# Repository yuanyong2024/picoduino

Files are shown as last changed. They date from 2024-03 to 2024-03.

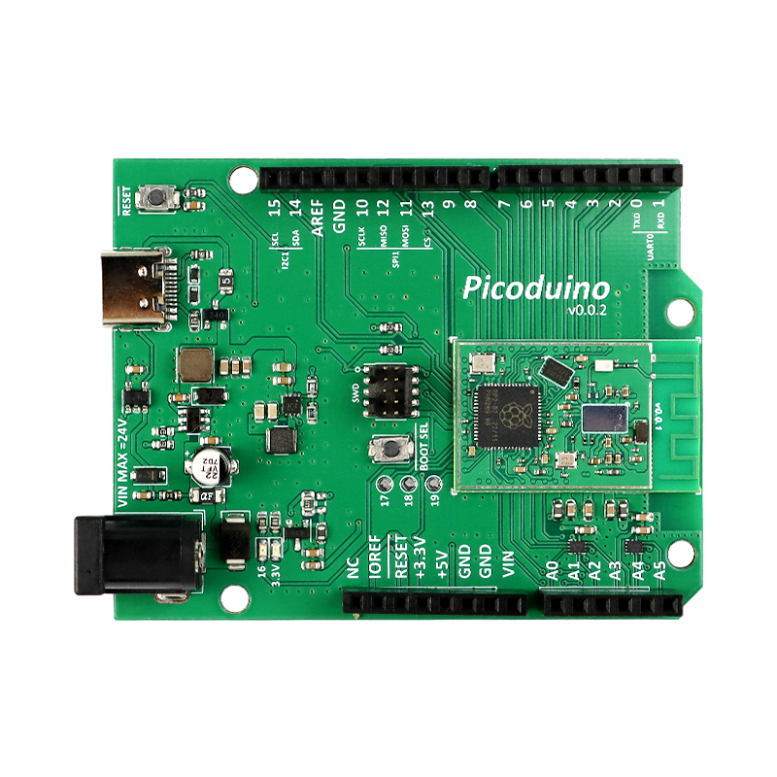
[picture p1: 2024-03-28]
pictures/6.jpg

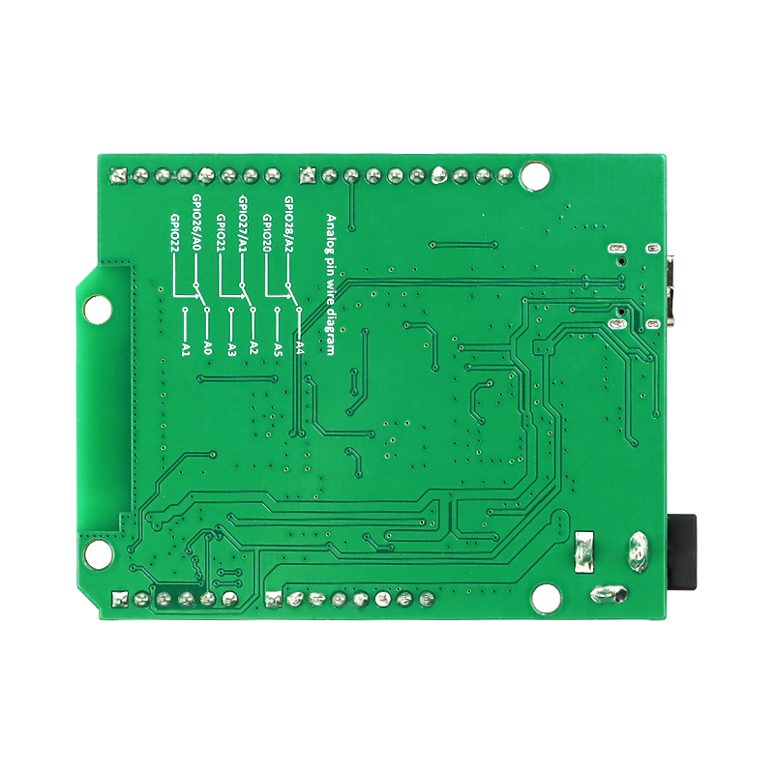
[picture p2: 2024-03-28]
pictures/5.jpg

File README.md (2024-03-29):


# Introduction
This is a Raspberry Pi Pico W hardware in arduino form factor.And it's name is picoduino

Unlike all the other wireless solutions for RP2040 on market(which almost all use the ESP wireless chip).
This board is equipped with a module that have the same chipsets like Pico W from Raspberry Pi. A microcontroller RP2040 from Raspberry Pi and a wireless chip CY43439 from Infineon.

# Features
1. totally compatible with arduino form factor.
2. fw developed for pico  w can easily ported to picoduino without any change(especially all the wireless features).
3. using analog switch so that 3 ADC ports can connect to 6 pins from A0 to A5 on picoduino board.
4. use a dedicated voltage reference to improve the accuracy of the ADC.
5. use two DC-DC regulators instead of LDO to improve the efficiency as well as increasing the maximum input voltage to 24V.
6. exposed all the GPIOs from RP2040 chip.
7. USB type C interface.
8. all the deisgn files are open-sourced and designed in Kicad.
    
# Limitations
1. During my test, I found out the antenna's performance still cannot match the official Pico w.
2. Still need more time and energy to tuning the antenna
3. No shield cover for the module on this version yet.
   
# considering support me?
Building the module and the picoduino definitley take time and energy.And also it's cost a lot. The module itself is a six layer board and I'm using the expensive Infineon chip. 
So I would appreciate anyone who can support me by purchase it from [this link](https://www.elecrow.com/picoduino.html)

# setup
For every board that you purchased, it's preflashed with a fw that can easily connect to local network as long as the wifi is available.
1. Plug picoduino to computer via USB type C cable.(A serial port should be available now)
2. Use some serial debug tool like arduino IDE's tool and type in your local WiFi name and then click send to send the WiFi name to picoduino.
3. it then will show the input WiFi name and ask you to type the password.
4. And send the password, picoduino will try to connect to the WiFi network with quick blink green led.
5. Once success, it will keep the green led on and you can copy the ip address to browser and then hit enter.
6. A webpage for controlling the green led is alive and you can control the led by click the webpage buttons.

setup_1

setup_2

# What's next?
After this picoduino, I will design a adafruit feather compatible one by using the same pico w module.
I will also make a programmable power supplier shield for picoduino.
## Stay tuned!

# useful links:
[pico w datasheet](https://datasheets.raspberrypi.com/picow/pico-w-datasheet.pdf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..)

[raspberry pi pico documentation](https://www.raspberrypi.com/documentation/microcontrollers/raspberry-pi-pico.html#raspberry-pi-pico-w)

[pico w module design file](https://github.com/yuanyong2024/pico_w_module)

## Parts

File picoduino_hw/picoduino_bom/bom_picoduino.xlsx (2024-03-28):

Ref | Qnty | Value | Footprint | PN | Vendor | Price(MOQ=100)
C1 | 1 | 47uF | Capacitor_SMD:CP_Elec_4x3 | EEEFT1V220AR | SAMSUNG | 1.02
C2, C6, C8, C11, C13, C14, C15, C16, C17, C18, C19 | 11 | 0.1uF | Capacitor_SMD:C_0603_1608Metric | 0603B104K500NT | FH | 0.014
C3 | 1 | 10nF | Capacitor_SMD:C_0603_1608Metric | 0603B103K500NT | FH | 0.015
C4,C7, C9, C20,C10 | 5 | 22uF | Capacitor_SMD:C_0603_1608Metric | CL10A226MP8NUNE | SAMSUNG | 0.084
C5, C12 | 2 | 4.7uF | Capacitor_SMD:C_0603_1608Metric | CL10A475KO8NNNC | SAMSUNG | 0.065
D1 | 1 | 30V | Diode_SMD:D_SMB | SSB44-E3/52T (https://item.szlcsc.com/472485.html) | VISHAY | 0.7
D2 | 1 | RED LED | LED_SMD:LED_0603_1608Metric | 19-213/R6C-AP1Q2B/5T | EVERLIGHT | 0.17
D4 | 1 | GREEN LED | LED_SMD:LED_0603_1608Metric | 19-213/GHC-XS1T1N/5T | EVERLIGHT | 0.3
D3 | 1 | 3A | Diode_SMD:D_SOD-123F | DSK34 | TWGMC | 0.16
D5 | 1 | 4.7V | Diode_SMD:D_SOD-123F | MMSZ4688T1G | onsemi | 0.27
D6, D7 | 2 | ESD5Zxx | Diode_SMD:D_SOD-523 | PESD5V0S1BB | TECH PUBLIC | 0.11
F1 | 1 | 500mA | Fuse:Fuse_1206_3216Metric | nSMD050-33V | luhai | 0.25
F2 | 1 | 500mA | Fuse:Fuse_0805_2012Metric | SMD0805B050TF | Brightking | 0.11
FB1, FB2, FB3 | 3 | FerriteBead | Inductor_SMD:L_0603_1608Metric | BLM18AG601SN1D | muRata | 0.037
J2 | 1 | Conn_ARM_JTAG_SWD_10 | Connector_PinHeader_1.27mm:PinHeader_2x05_P1.27mm_Vertical_SMD | HB-PH9-12725PB2GOB | HANBO | 0.45
J3 | 1 | USB_C_Receptacle_USB2.0 | Connector_USB:USB_C_Receptacle_HRO_TYPE-C-31-M-12 | TYPE-C 16PIN 2MD(073) | SHOU HAN | 0.28
J4, J7 | 2 | Conn_01x08 | Connector_PinSocket_2.54mm:PinSocket_1x08_P2.54mm_Vertical | PM254-1-08-Z-8.5 | HCTL | 0.65
J5 | 1 | Barrel_Jack_Switch_Pin3Ring | Connector_BarrelJack:BarrelJack_GCT_DCJ200-10-A_Horizontal | DC-005-20A | HRO | 0.46
J8 | 1 | Conn_01x10 | Connector_PinSocket_2.54mm:PinSocket_1x10_P2.54mm_Vertical | PM254-1-10-Z-8.5 | HCTL | 0.77
J9 | 1 | Conn_01x06 | Connector_PinSocket_2.54mm:PinSocket_1x06_P2.54mm_Vertical | PM254-1-06-W-8.5 | HCTL | 0.61
L1 | 1 | 6.8uH | Inductor_SMD:L_Abracon_ASPI-4030S | YHNR4020-6R8M | YJYCOIN | 0.45
L2 | 1 | 1.5uH | Inductor_SMD:L_Abracon_ASPI-3012S | FNR3012S1R5NT | CJIANG | 0.212
Q1 | 1 | FDN340P | Package_TO_SOT_SMD:SOT-23 | FDN340P | TECH PUBLIC | 0.3
R1 | 1 | 6K | Resistor_SMD:R_0805_2012Metric | 0603WAF1002T5E (https://item.szlcsc.com/26547.html) | UNI-ROYAL | 0.0057
R3 | 1 | 62K 1% | Resistor_SMD:R_0603_1608Metric | 0603WAF6202T5E | UNI-ROYAL | 0.0067
R4 | 1 | 12K 1% | Resistor_SMD:R_0603_1608Metric | 0603WAF1202T5E | UNI-ROYAL | 0.0061
R5, R13 | 2 | 4.7K | Resistor_SMD:R_0603_1608Metric | 0603WAF4701T5E | UNI-ROYAL | 0.0065
R12 | 1 | 10K | Resistor_SMD:R_0603_1608Metric | 0603WAF1002T5E | UNI-ROYAL | 0.0057
R6 | 1 | 1M | Resistor_SMD:R_0603_1608Metric | 0603WAF1004T5E | UNI-ROYAL | 0.006
R7, R11 | 2 | DNI | Resistor_SMD:R_0603_1608Metric
R8 | 1 | 20K 1% | Resistor_SMD:R_0603_1608Metric | 0603WAF2002T5E (https://item.szlcsc.com/4591.html) | UNI | 0.006
R9 | 1 | 90K 1% | Resistor_SMD:R_0603_1608Metric | 0603WAF9002T5E (https://item.szlcsc.com/2905674.html) | UNI-ROYAL | 0.006
R10, R14 | 2 | 1K | Resistor_SMD:R_0603_1608Metric | 0603WAF1001T5E | UNI-ROYAL | 0.005
R15, R16 | 2 | 5.1K | Resistor_SMD:R_0603_1608Metric | 0603WAF5101T5E | UNI-ROYAL | 0.006
SW1, SW2 | 2 | ~ | Button_Switch_SMD:SW_Push_SPST_NO_Alps_SKRK | YTS1C0191ABG00N | YIYUAN | 0.46
U1 | 1 | PICO_M | kiCadPcbLib:PICO_M
U2 | 1 | RT5797ALGQW | Package_DFN_QFN:DFN-8-1EP_2x2mm_P0.5mm_EP0.6x1.2mm | RT5797ALGQW | RICHTEK | 1.6
U3 | 1 | RT8259GE | Package_TO_SOT_SMD:SOT-23-6 | RT8259GE | RICHTEK | 2.5
U4 | 1 | OP | Package_TO_SOT_SMD:TSOT-23-5 | TL081HIDBVR | TI | 0.7
U5 | 1 | LM4040DBZ-3.0 | Package_TO_SOT_SMD:SOT-23-3 | LM4040B30FTA | DIODES | 2.84
U6, U7 | 2 | RS2118YUTQK10 | Package_DFN_QFN:UQFN-10_1.4x1.8mm_P0.4mm | RS2118YUTQK10 | RUNIC | 1.55

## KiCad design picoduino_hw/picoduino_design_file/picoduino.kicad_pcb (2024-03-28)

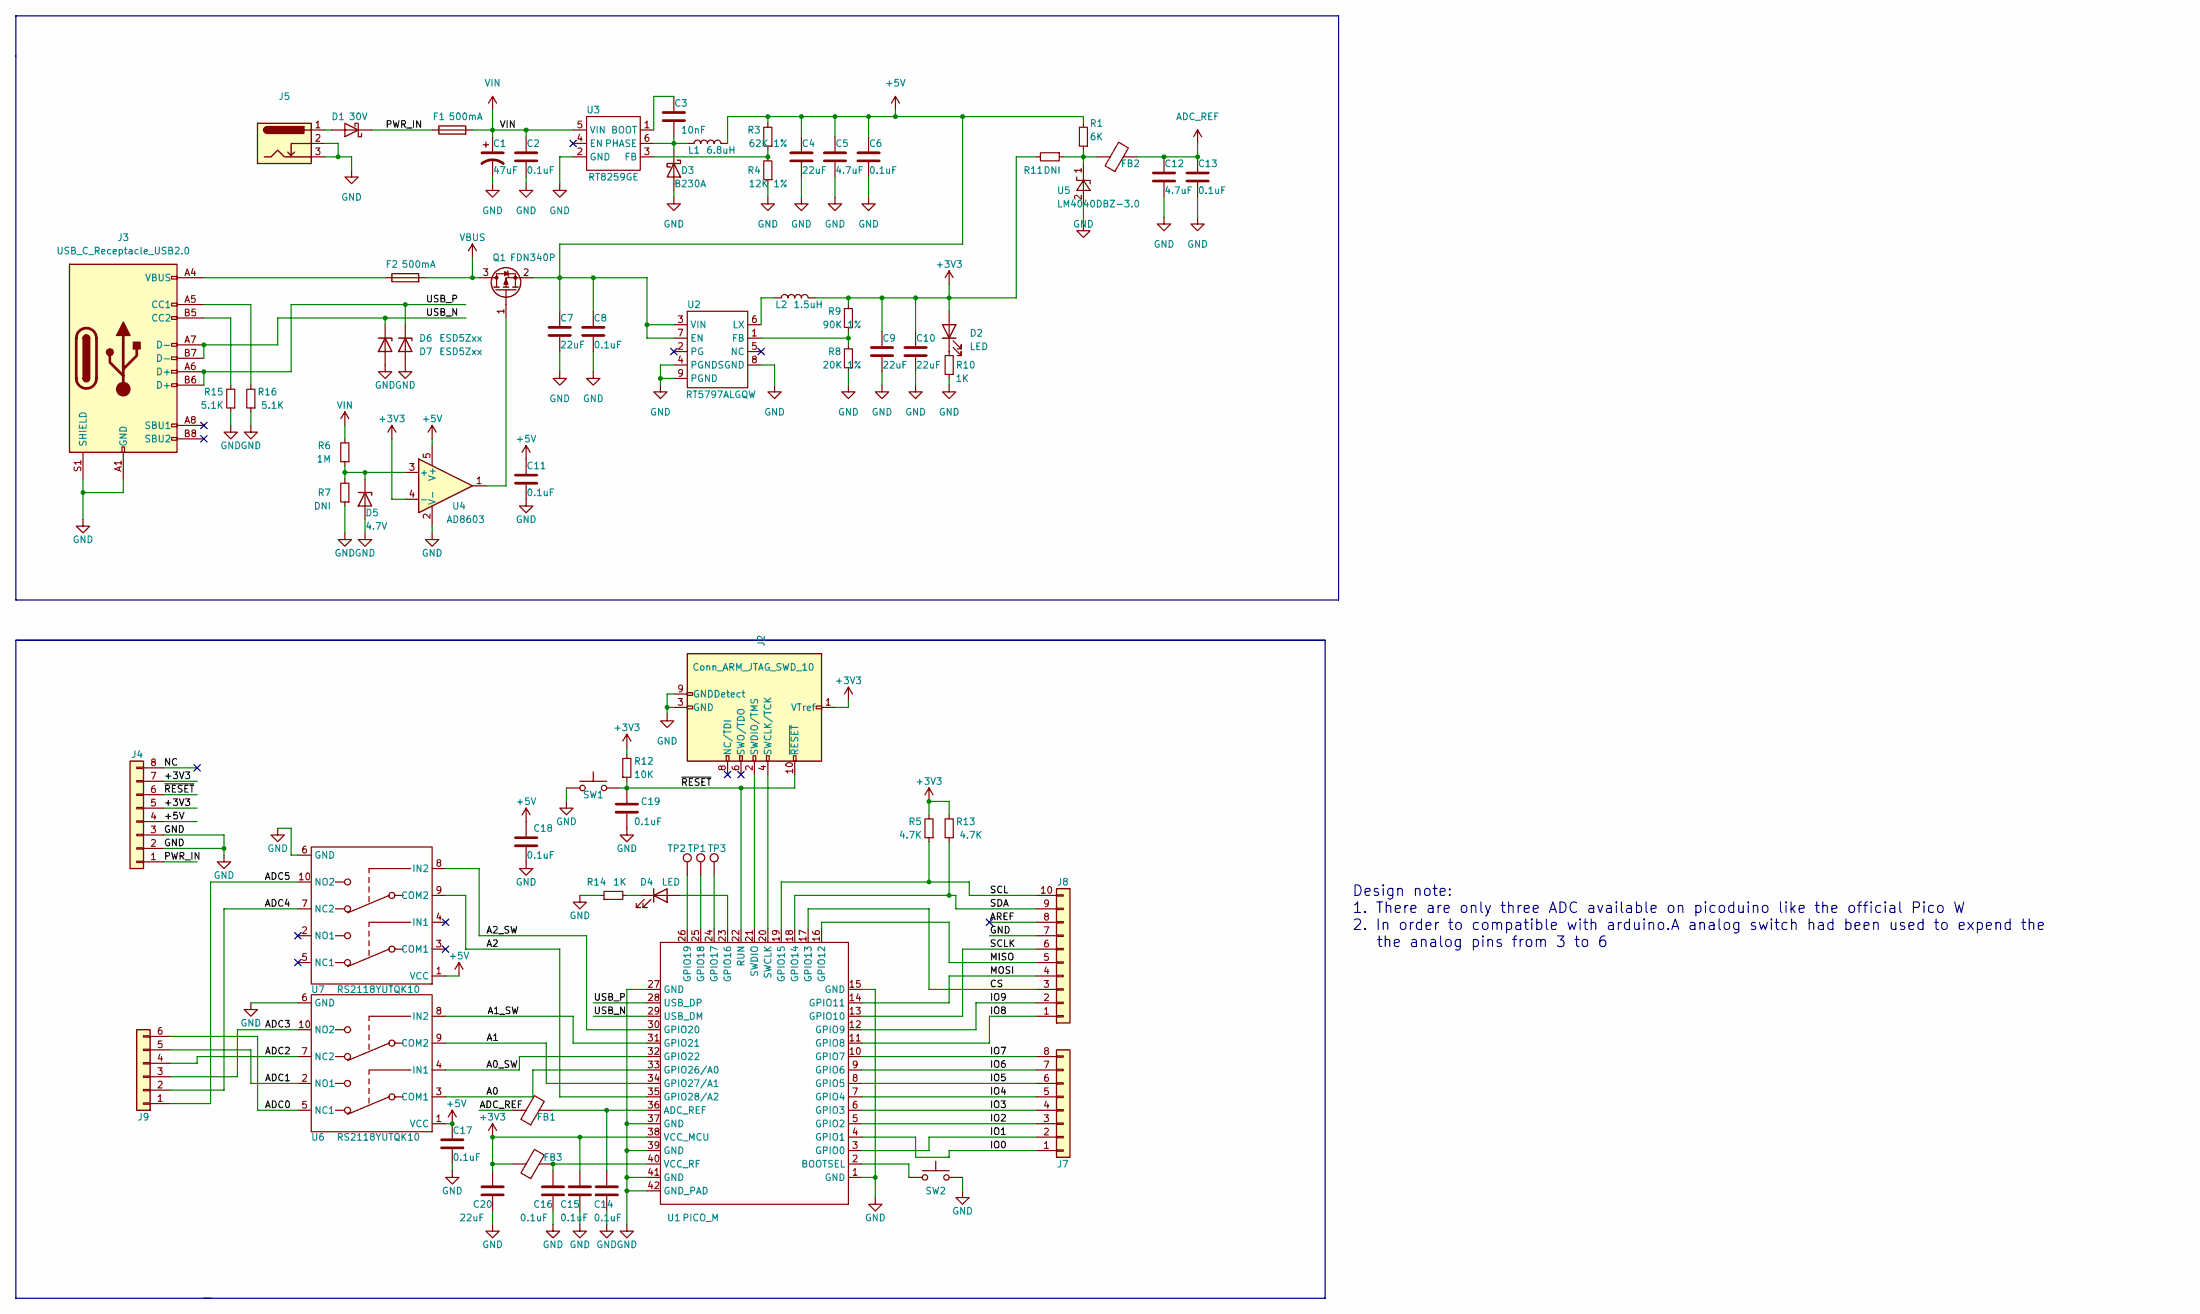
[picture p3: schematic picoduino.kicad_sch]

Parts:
C1: 47uF; CP_Elec_4x3
C2, C6, C8, C11, C13, C14, C15, C16, C17, C18, C19: 0.1uF; C_0603_1608Metric
C3: 10nF; C_0603_1608Metric
C4, C7, C9, C10, C20: 22uF; C_0603_1608Metric
C5, C12: 4.7uF; C_0603_1608Metric
D1: 30V; D_SMA
D2, D4: LED; LED_0603_1608Metric
D3: B230A; D_SOD-123F
D5: 4.7V; D_SOD-123F
D6, D7: ESD5Zxx; D_SOD-523
F1: 500mA; Fuse_1206_3216Metric
F2: 500mA; Fuse_0805_2012Metric
FB1, FB2, FB3: FerriteBead; L_0603_1608Metric
J2: Conn_ARM_JTAG_SWD_10; PinHeader_2x05_P1.27mm_Vertical_SMD
J3: USB_C_Receptacle_USB2.0; USB_C_Receptacle_HRO_TYPE-C-31-M-12
J4, J7: Conn_01x08; PinSocket_1x08_P2.54mm_Vertical
J5: Barrel_Jack_Switch_Pin3Ring; BarrelJack_GCT_DCJ200-10-A_Horizontal
J8: Conn_01x10; PinSocket_1x10_P2.54mm_Vertical
J9: Conn_01x06; PinSocket_1x06_P2.54mm_Vertical
L1: 6.8uH; L_Abracon_ASPI-4030S
L2: 1.5uH; L_Abracon_ASPI-3012S
Q1: FDN340P; SOT-23
R1: 6K; R_0805_2012Metric
R3: 62K 1%; R_0603_1608Metric
R4: 12K 1%; R_0603_1608Metric
R5, R13: 4.7K; R_0603_1608Metric
R6: 1M; R_0603_1608Metric
R7, R11: DNI; R_0603_1608Metric
R8: 20K 1%; R_0603_1608Metric
R9: 90K 1%; R_0603_1608Metric
R10, R14: 1K; R_0603_1608Metric
R12: 10K; R_0603_1608Metric
R15, R16: 5.1K; R_0603_1608Metric
SW1, SW2: SW_Push_SPST_NO_Alps_SKRK
TP1, TP2, TP3: TestPoint; TestPoint_Pad_D1.5mm
U1: PICO_M
U2: RT5797ALGQW; DFN-8-1EP_2x2mm_P0.5mm_EP0.6x1.2mm
U3: RT8259GE; SOT-23-6
U4: AD8603; TSOT-23-5
U5: LM4040DBZ-3.0; SOT-23-3
U6, U7: RS2118YUTQK10; UQFN-10_1.4x1.8mm_P0.4mm

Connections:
+1V2: C1.1, C2.1, F1.2, R6.2, U3.5 (VIN)
+3V3: C9.2, C10.2, C15.2, C20.2, D2.2 (A), FB3.1, J2.1 (VTref), J4.5, J4.7, L2.2, R5.2, R9.2, R11.2, R12.2, R13.2, U1.38 (VCC_MCU), U4.4 (-)
+5V: C4.2, C5.2, C6.2, C7.2, C8.2, C11.2, C17.2, C18.2, J4.4, L1.2, Q1.2 (S), R1.2, R3.2, U2.3 (VIN), U2.7 (EN), U4.5 (V+), U6.1 (VCC), U7.1 (VCC)
/A0: U1.33 (GPIO26/A0), U6.3 (COM1)
/A0_SW: U1.32 (GPIO22), U6.4 (IN1)
/A1: U1.34 (GPIO27/A1), U6.9 (COM2)
/A1_SW: U1.31 (GPIO21), U6.8 (IN2)
/A2: U1.35 (GPIO28/A2), U7.9 (COM2)
/A2_SW: U1.30 (GPIO20), U7.8 (IN2)
/ADC0: J9.6, U6.5 (NC1)
/ADC1: J9.5, U6.2 (NO1)
/ADC2: J9.4, U6.7 (NC2)
/ADC3: J9.3, U6.10 (NO2)
/ADC4: J9.2, U7.7 (NC2)
/ADC5: J9.1, U7.10 (NO2)
/AREF: J8.8
/CS: J8.3, U1.17 (GPIO13)
/IO0: J7.1, U1.4 (GPIO1)
/IO1: J7.2, U1.3 (GPIO0)
/IO2: J7.3, U1.5 (GPIO2)
/IO3: J7.4, U1.6 (GPIO3)
/IO4: J7.5, U1.7 (GPIO4)
/IO5: J7.6, U1.8 (GPIO5)
/IO6: J7.7, U1.9 (GPIO6)
/IO7: J7.8, U1.10 (GPIO7)
/IO8: J8.1, U1.11 (GPIO8)
/IO9: J8.2, U1.12 (GPIO9)
/MISO: J8.5, U1.16 (GPIO12)
/MOSI: J8.4, U1.14 (GPIO11)
/NC: J4.8
/PWR_IN: D1.1 (K), F1.1, J4.1
/SCL: J8.10, R5.1, U1.19 (GPIO15)
/SCLK: J8.6, U1.13 (GPIO10)
/SDA: J8.9, R13.1, U1.18 (GPIO14)
/USB_N: D6.1 (K), J3.A7 (D-), J3.B7 (D-), U1.29 (USB_DM)
/USB_P: D7.1 (K), J3.A6 (D+), J3.B6 (D+), U1.28 (USB_DP)
/~RESET: C19.2, J2.10 (~RESET), J4.6, R12.1, SW1.1, U1.22 (RUN)
ADC_REF: C12.2, C13.2, FB1.1, FB2.2; also elsewhere on the board
GND: C1.2, C2.2, C4.1, C5.1, C6.1, C7.1, C8.1, C9.1, C10.1, C11.1, C12.1, C13.1, C14.1, C15.1, C16.1, C17.1, C18.1, C19.1, C20.1, D3.2 (A), D5.2 (A), D6.2 (A), D7.2 (A), J2.3 (GND), J2.5 (GND), J2.9 (GNDDetect), J3.A1 (GND), J3.A12 (GND), J3.B1 (GND), J3.B12 (GND), J3.S1 (SHIELD), J4.2, J4.3, J5.2, J5.3, J8.7, R4.1, R7.1, R8.1, R10.1, R14.1, R15.1, R16.1, SW1.2, SW2.2, U1.1 (GND), U1.15 (GND), U1.27 (GND), U1.37 (GND), U1.39 (GND), U1.41 (GND), U1.42 (GND_PAD), U2.4 (PGND), U2.8 (SGND), U2.9 (PGND), U3.2 (GND), U4.2 (V-), U5.2 (A), U6.6 (GND), U7.6 (GND)
unnamed: D1.2 (A), J5.1
unnamed: D2.1 (K), R10.2
unnamed: C3.1, D3.1 (K), L1.1, U3.6 (PHASE)
unnamed: D4.2 (A), U1.23 (GPIO16)
unnamed: D4.1 (K), R14.2
unnamed: D5.1 (K), R6.1, R7.2, U4.3 (+)
unnamed: F2.1, J3.A4 (VBUS), J3.A9 (VBUS), J3.B4 (VBUS), J3.B9 (VBUS)
unnamed: J2.4 (SWCLK/TCK), U1.20 (SWCLK)
unnamed: J2.2 (SWDIO/TMS), U1.21 (SWDIO)
unnamed: J3.A5 (CC1), R16.2
unnamed: J3.B5 (CC2), R15.2
unnamed: Q1.1 (G), U4.1
unnamed: C14.2, FB1.2, U1.36 (ADC_REF)
unnamed: SW2.1, U1.2 (BOOTSEL)
unnamed: TP1.1, U1.24 (GPIO17)
unnamed: TP3.1, U1.25 (GPIO18)
unnamed: TP2.1, U1.26 (GPIO19)
unnamed: C16.2, FB3.2, U1.40 (VCC_RF)
unnamed: R8.2, R9.1, U2.1 (FB)
unnamed: L2.1, U2.6 (LX)
unnamed: C3.2, U3.1 (BOOT)
unnamed: R3.1, R4.2, U3.3 (FB)
unnamed 61: FB2.1, R1.1, R11.1, U5.1 (K); also elsewhere on the board
VBUS: F2.2, Q1.3 (D)

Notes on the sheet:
Design note: 1. There are only three ADC available on picoduino like the official Pico W 2. In order to compatible with arduino.A analog switch had been used to expend the the analog pins from 3 to 6

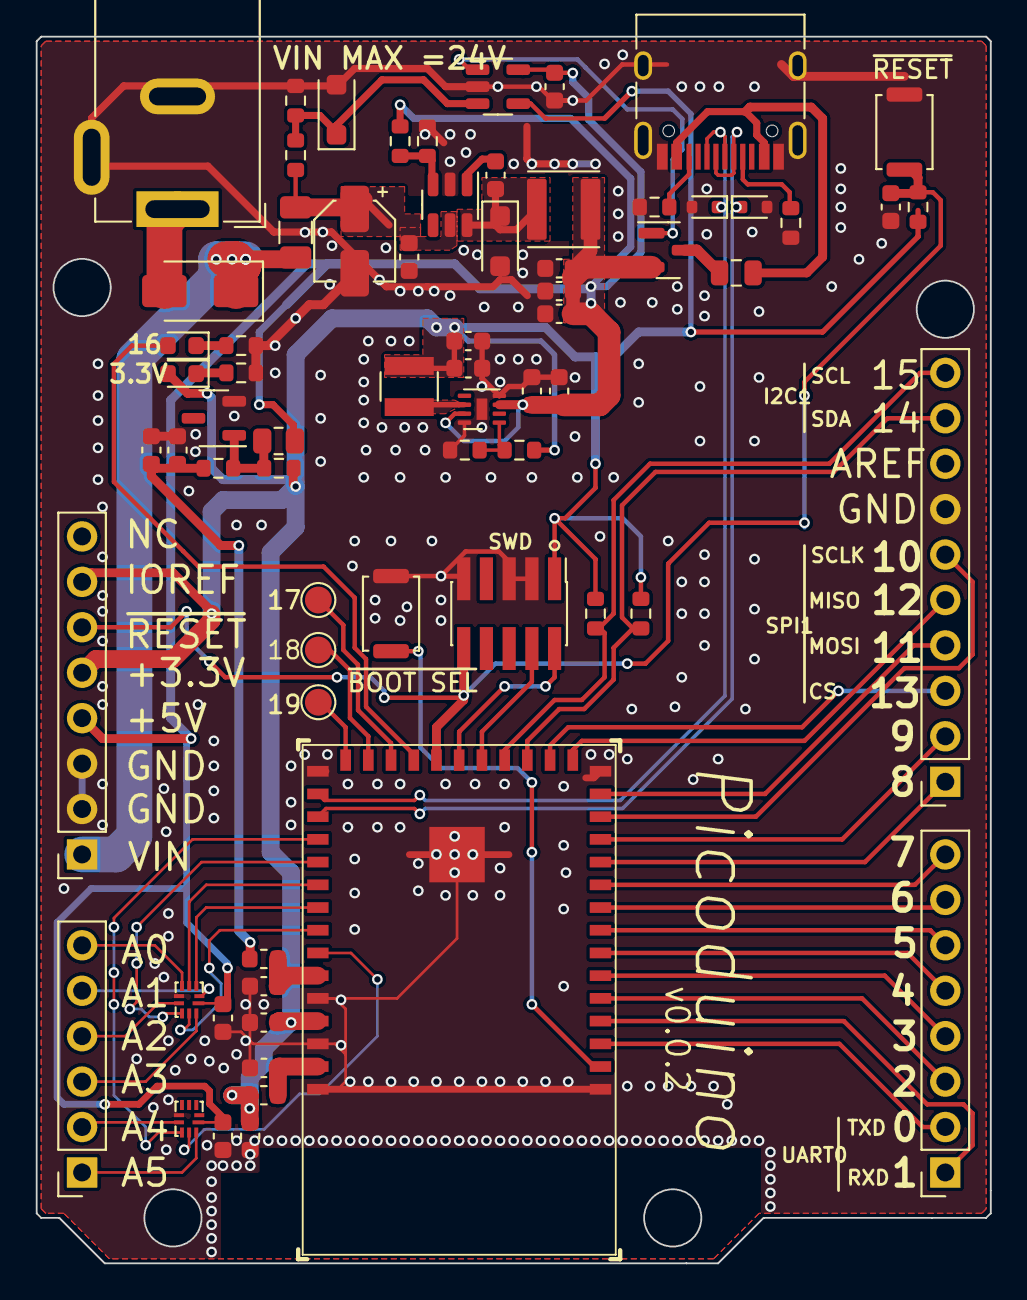
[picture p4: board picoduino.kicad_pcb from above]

Board: 2 copper layers, 53.3 x 68.6 mm, 69 parts (0 on the bottom side), 61 nets.

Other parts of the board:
R2: 0R; R_0603_1608Metric

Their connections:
ADC_REF: R2.1; also elsewhere on the board
unnamed 61: R2.2; also elsewhere on the board

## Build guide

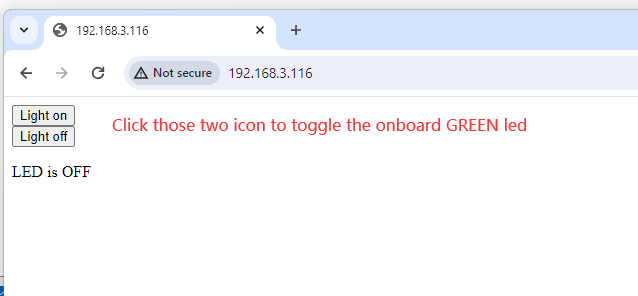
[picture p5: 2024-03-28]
pictures/setup_2.png

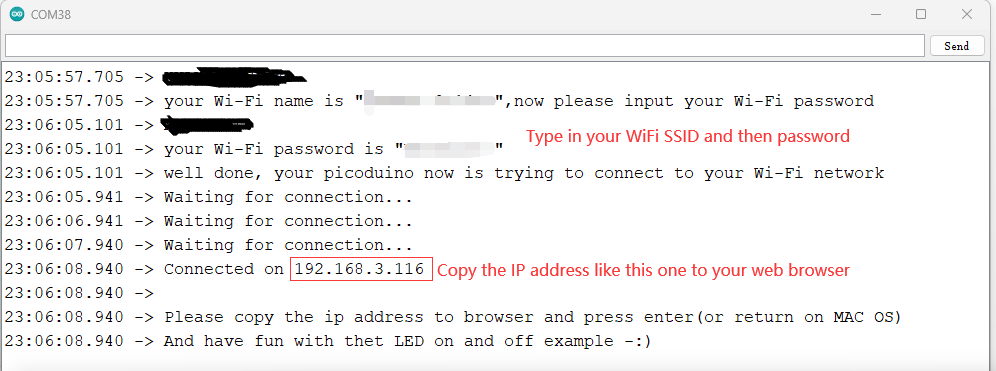
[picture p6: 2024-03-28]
pictures/setup_1.png

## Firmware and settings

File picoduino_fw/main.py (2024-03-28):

from machine import UART,Pin,I2C
import network
import socket
import time

led = Pin(16,Pin.OUT)
led.value(1)

timeout_count = 2
while timeout_count:
    print(f"timeout count {timeout_count} before setting up the Wi-Fi config")
    timeout_count-=1
    time.sleep(1)
    
print("\r\nWelcome to the setup process for picoduino, Please follow below three steps to control the onboard led via browser\r\n")
print('Please input your Wi-Fi name:')
wifi_name = input()
print(f'your Wi-Fi name is "{wifi_name}",now please input your Wi-Fi password')
password = input()
print(f'your Wi-Fi password is "{password}"')
print("well done, your picoduino now is trying to connect to your Wi-Fi network")




#connect to wifi router and return the ip
def connect():
    #Connect to WLAN
    wlan = network.WLAN(network.STA_IF)
    wlan.active(True)
    wlan.connect(wifi_name, password)
    retry_count = 10
    while wlan.isconnected() == False:
        print('Waiting for connection...')
        #blink for 1s insted of delay 1s
        for i in range(5):
            led.value(0)
            time.sleep(0.1)
            led.value(1)
            time.sleep(0.1)
            
        retry_count-=1
        if retry_count==0:
            break
    
    if retry_count == 0:
        print("ooops, picoduino cannot connect to you Wi-Fi network, please check your Wi-Fi name and password and press reset button for a pretry.!!!!!!!!!!")
        while True:
            led.value(0)
            time.sleep(1)
            led.value(1)
            time.sleep(1)
        
    led.value(1)   
    ip = wlan.ifconfig()[0]
    print(f'Connected on {ip}')
    print("\r\nPlease copy the above ip address to browser and press enter(or return on MAC OS)")
    print("And have fun with thet LED on and off example -:)")
    return ip

  
def open_socket(ip):
    # Open a socket
    address = (ip, 80)
    connection = socket.socket()
    connection.bind(address)
    connection.listen(1)
    return connection


  
#only turn on and off led in webpaage.  
def webpage(state):
    #Template HTML
    html = f"""
            <!DOCTYPE html>
            <html>
            <form action="./lighton">
            <input type="submit" value="Light on" />
            </form>
            <form action="./lightoff">
            <input type="submit" value="Light off" />
            </form>
            <p>LED is {state}</p>
            </body>
            </html>
            """
    return str(html)
    
    
#start a web server    
def serve(connection):
    #Start a web server
    state = 'OFF'
    temperature = 0
    while True:
        client = connection.accept()[0]
        request = client.recv(1024)
        request = str(request)
        try:
            request = request.split()[1]
        except IndexError:
            pass
        if request == '/lighton?':
            led.value(1)
            state = 'ON'
            print("LED is on now")
        elif request =='/lightoff?':
            led.value(0)
            state = 'OFF'
            print("LED is off now")
        client.send(webpage(state))
        client.close()
        
        
        
try:
    ip = connect()
    connection = open_socket(ip)
    serve(connection)
except KeyboardInterrupt:
    machine.reset()
        

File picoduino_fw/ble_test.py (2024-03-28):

# This example demonstrates a simple temperature sensor peripheral.
#
# The sensor's local value is updated, and it will notify
# any connected central every 10 seconds.

import bluetooth
import random
import struct
import time
import machine
import ubinascii
#from ble_advertising import advertising_payload
from micropython import const
from machine import Pin


_ADV_TYPE_FLAGS = const(0x01)
_ADV_TYPE_NAME = const(0x09)
_ADV_TYPE_UUID16_COMPLETE = const(0x3)
_ADV_TYPE_UUID32_COMPLETE = const(0x5)
_ADV_TYPE_UUID128_COMPLETE = const(0x7)
_ADV_TYPE_UUID16_MORE = const(0x2)
_ADV_TYPE_UUID32_MORE = const(0x4)
_ADV_TYPE_UUID128_MORE = const(0x6)
_ADV_TYPE_APPEARANCE = const(0x19)



_IRQ_CENTRAL_CONNECT = const(1)
_IRQ_CENTRAL_DISCONNECT = const(2)
_IRQ_GATTS_INDICATE_DONE = const(20)

_FLAG_READ = const(0x0002)
_FLAG_NOTIFY = const(0x0010)
_FLAG_INDICATE = const(0x0020)

# org.bluetooth.service.environmental_sensing
_ENV_SENSE_UUID = bluetooth.UUID(0x181A)
# org.bluetooth.characteristic.temperature
_TEMP_CHAR = (
    bluetooth.UUID(0x2A6E),
    _FLAG_READ | _FLAG_NOTIFY | _FLAG_INDICATE,
)
_ENV_SENSE_SERVICE = (
    _ENV_SENSE_UUID,
    (_TEMP_CHAR,),
)

# org.bluetooth.characteristic.gap.appearance.xml
_ADV_APPEARANCE_GENERIC_THERMOMETER = const(768)


# Generate a payload to be passed to gap_advertise(adv_data=...).
def advertising_payload(limited_disc=False, br_edr=False, name=None, services=None, appearance=0):
    payload = bytearray()

    def _append(adv_type, value):
        nonlocal payload
        payload += struct.pack("BB", len(value) + 1, adv_type) + value

    _append(
        _ADV_TYPE_FLAGS,
        struct.pack("B", (0x01 if limited_disc else 0x02) + (0x18 if br_edr else 0x04)),
    )

    if name:
        _append(_ADV_TYPE_NAME, name)

    if services:
        for uuid in services:
            b = bytes(uuid)
            if len(b) == 2:
                _append(_ADV_TYPE_UUID16_COMPLETE, b)
            elif len(b) == 4:
                _append(_ADV_TYPE_UUID32_COMPLETE, b)
            elif len(b) == 16:
                _append(_ADV_TYPE_UUID128_COMPLETE, b)

    # See org.bluetooth.characteristic.gap.appearance.xml
    if appearance:
        _append(_ADV_TYPE_APPEARANCE, struct.pack("<h", appearance))

    return payload

class BLETemperature:
    def __init__(self, ble, name=""):
        self._sensor_temp = machine.ADC(4)
        self._ble = ble
        self._ble.active(True)
        self._ble.irq(self._irq)
        ((self._handle,),) = self._ble.gatts_register_services((_ENV_SENSE_SERVICE,))
        self._connections = set()
        if len(name) == 0:
            name = 'Picoduino %s' % ubinascii.hexlify(self._ble.config('mac')[1],':').decode().upper()
        print('Sensor name %s' % name)
        self._payload = advertising_payload(
            name=name, services=[_ENV_SENSE_UUID]
        )
        self._advertise()

    def _irq(self, event, data):
        # Track connections so we can send notifications.
        if event == _IRQ_CENTRAL_CONNECT:
            conn_handle, _, _ = data
            self._connections.add(conn_handle)
        elif event == _IRQ_CENTRAL_DISCONNECT:
            conn_handle, _, _ = data
            self._connections.remove(conn_handle)
            # Start advertising again to allow a new connection.
            self._advertise()
        elif event == _IRQ_GATTS_INDICATE_DONE:
            conn_handle, value_handle, status = data

    def update_temperature(self, notify=False, indicate=False):
        # Write the local value, ready for a central to read.
        temp_deg_c = self._get_temp()
        print("write temp %.2f degc" % temp_deg_c);
        self._ble.gatts_write(self._handle, struct.pack("<h", int(temp_deg_c * 100)))
        if notify or indicate:
            for conn_handle in self._connections:
                if notify:
                    # Notify connected centrals.
                    self._ble.gatts_notify(conn_handle, self._handle)
                if indicate:
                    # Indicate connected centrals.
                    self._ble.gatts_indicate(conn_handle, self._handle)

    def _advertise(self, interval_us=500000):
        self._ble.gap_advertise(interval_us, adv_data=self._payload)

    # ref https://github.com/raspberrypi/pico-micropython-examples/blob/master/adc/temperature.py
    def _get_temp(self):
        conversion_factor = 3.3 / (65535)
        reading = self._sensor_temp.read_u16() * conversion_factor
        
        # The temperature sensor measures the Vbe voltage of a biased bipolar diode, connected to the fifth ADC channel
        # Typically, Vbe = 0.706V at 27 degrees C, with a slope of -1.721mV (0.001721) per degree. 
        return 27 - (reading - 0.706) / 0.001721
        
def demo():
    ble = bluetooth.BLE()
    temp = BLETemperature(ble)
    counter = 0
    led = Pin('LED', Pin.OUT)
    while True:
        if counter % 10 == 0:
            temp.update_temperature(notify=True, indicate=False)
        led.toggle()
        time.sleep_ms(1000)
        counter += 1

if __name__ == "__main__":
    demo()
